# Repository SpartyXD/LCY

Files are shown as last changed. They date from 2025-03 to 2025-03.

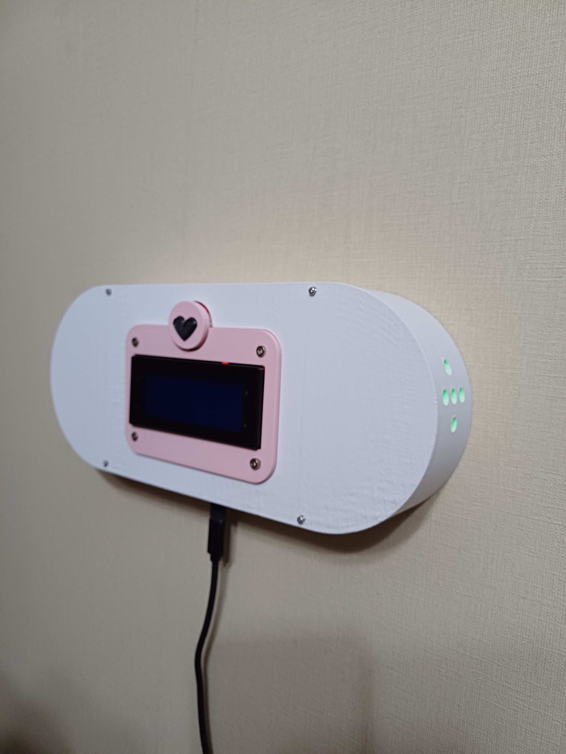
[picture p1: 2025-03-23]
Images/Foto bonita.jpg

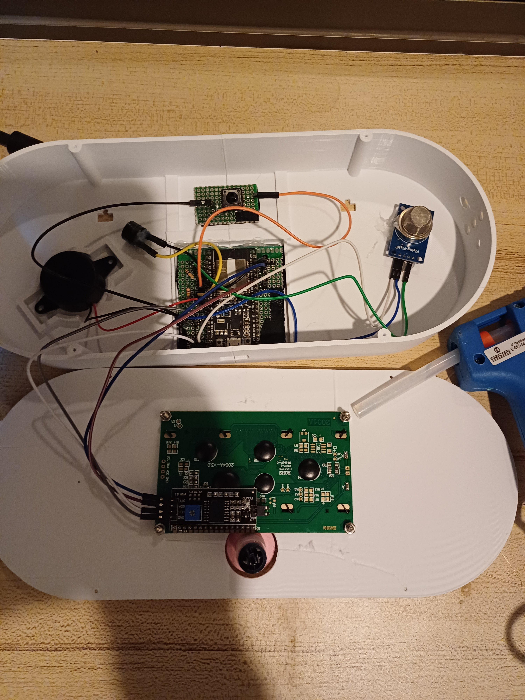
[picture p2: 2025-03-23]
Images/Circuito interno.jpg

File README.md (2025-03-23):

# LCY
Robot que le hice a mi abuelita para que pueda recibir mensajes / estar atenta al gas de la cocina :p 

Puede ser impreso con la combinacion de colores que quieras!

## Proceso de desarrollo
El robot tuvo cambios drasticos en el diseño principalmente porque no calcule bien el espacio de mi impresora 3D, asi que el chasis viene dividido en 2 partes (left - right)

La idea es imprimir una de cada pieza y el circuito hacerlo en una perfboard siguiendo las conexiones que estan en el mockup (pines a eleccion libre)

Implementacion completa

Ensamble

Render_3D

Primer_mock_up

## Componentes usados
* Sensor MQ-2 de gas
* Buzzer pasivo
* Buzzer activo de 12V
* ESP32 WROOM32 DEVKIT
* Headers / Perfboard / Cables
* Pantalla LCD I2C 20x4
* Switch simple (boton)

## Implementacion
El codigo viene listo a modo de proyecto en PlatformIO, solo se debe crear un nuevo proyecto y copiar la carpeta **/src** junto al archivo **platform.ini**.
Para poder usar la funcionalidad de mensajes, se debe crear un bot el telegram usando BOTFather y reemplazando la id en el archivo **chatbot.h** eso, junto a colocar la clave de tu internet en el archivo **main.cpp**

## Modos

### Idle
Pantalla apagada actualizando mediciones de gas y chequeando mensajes entrantes

### Sensor de gas
Al apretar el boton en modo idle se cambia a este modo: muestra la medicion actual del sensor de gas

### Mensajes
Se activa cuando se recibe un mensaje en el bot de telegram, se activa el mini buzzer y alerta al usuario que enviaron un mensaje, pulsa el boton para marcarlo como "recibido"

### Fuga de gas
Se activa cuando se detecta un nivel anormal de gas en el ambiente, enciende la alarma principal (muy fuerte) hasta que se aprete el boton indicando que se corto el gas o bien cuando los niveles vuelvan a la normalidad.

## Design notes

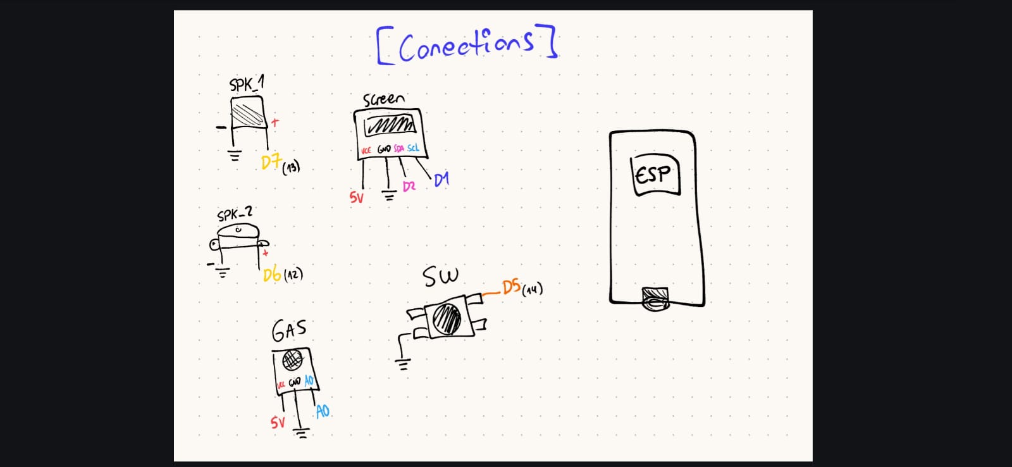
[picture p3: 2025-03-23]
Images/Connections.jpg

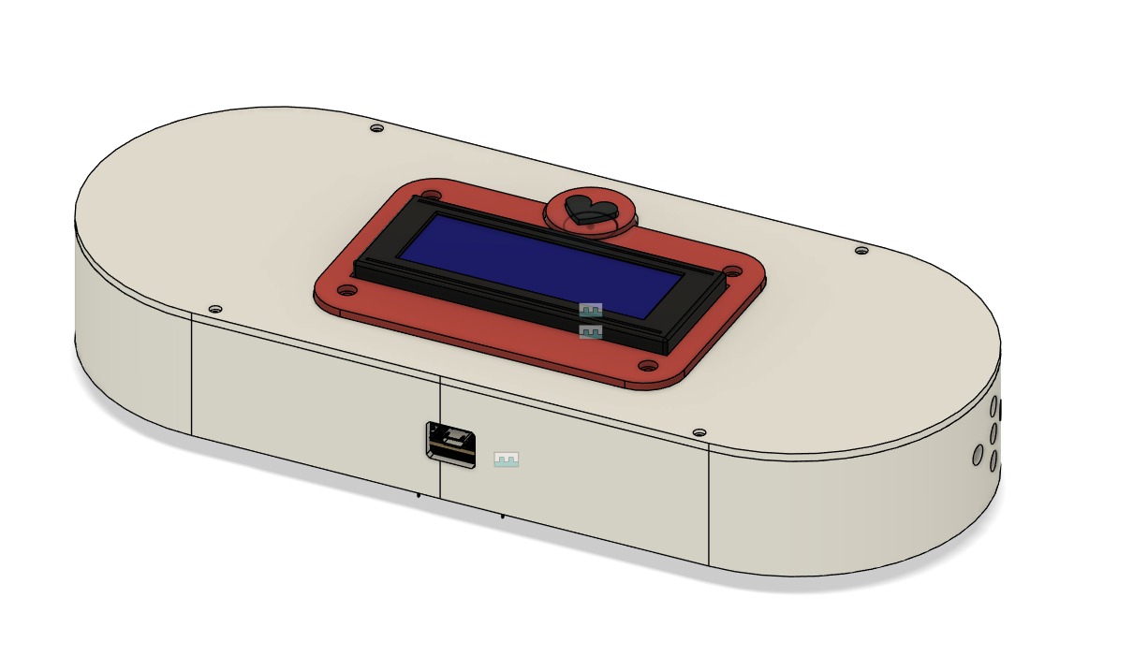
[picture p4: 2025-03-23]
Images/Render_3D.jpg

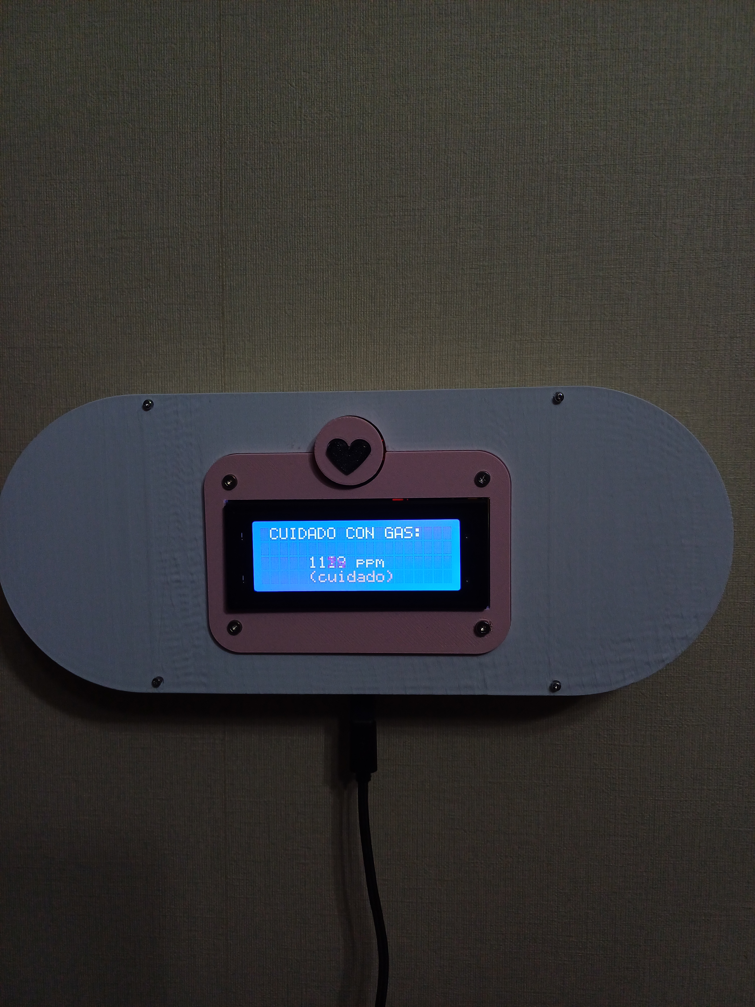
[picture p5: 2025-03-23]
Images/Funcando.jpg

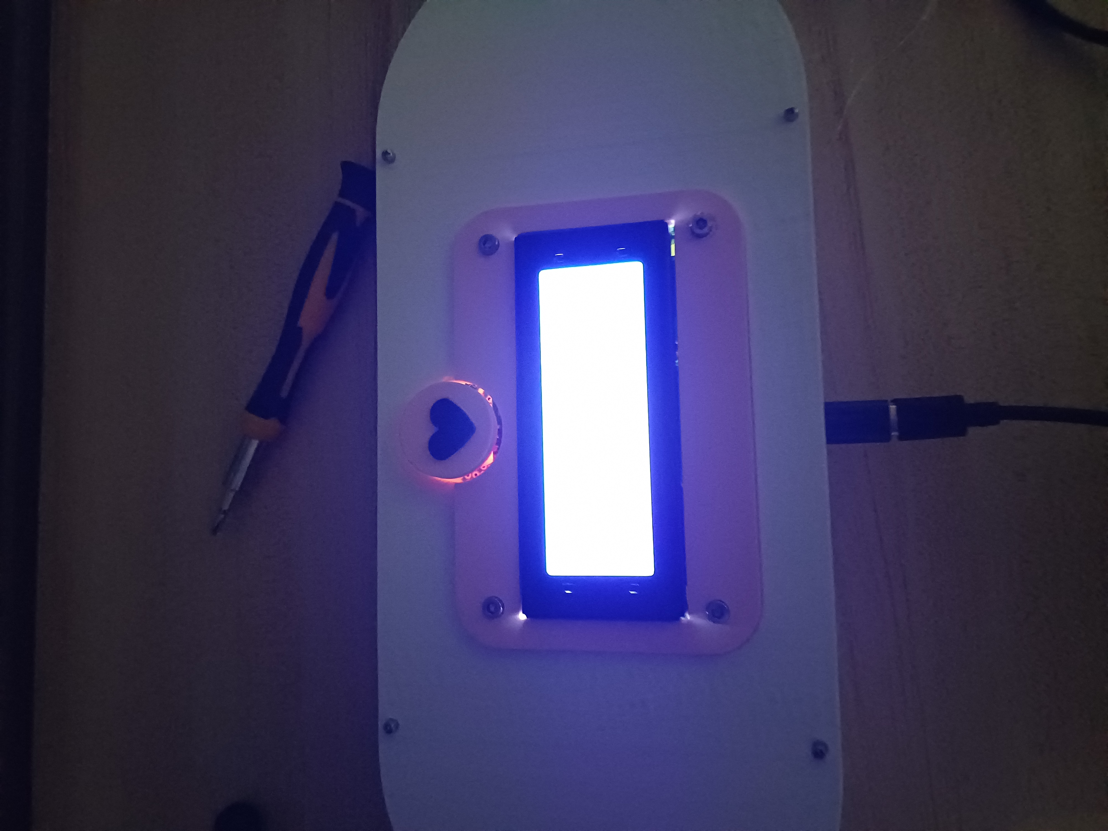
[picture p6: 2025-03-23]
Images/Foto epica.jpg

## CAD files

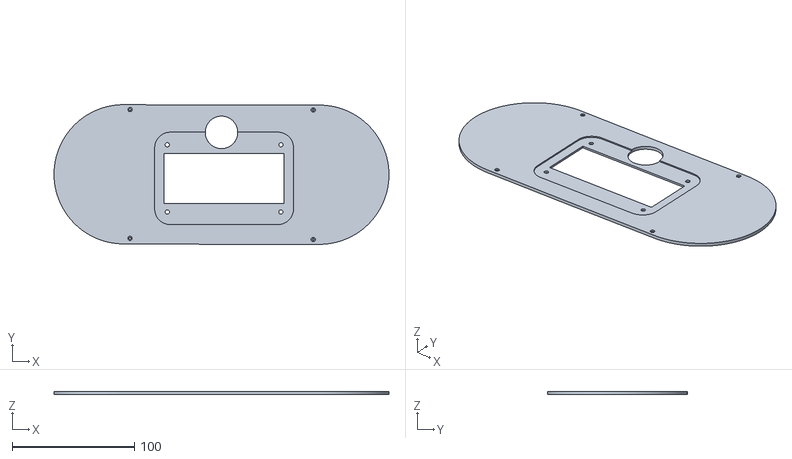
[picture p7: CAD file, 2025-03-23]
3D Files/Top_plate.stl
274.3 x 114.4 x 2.50

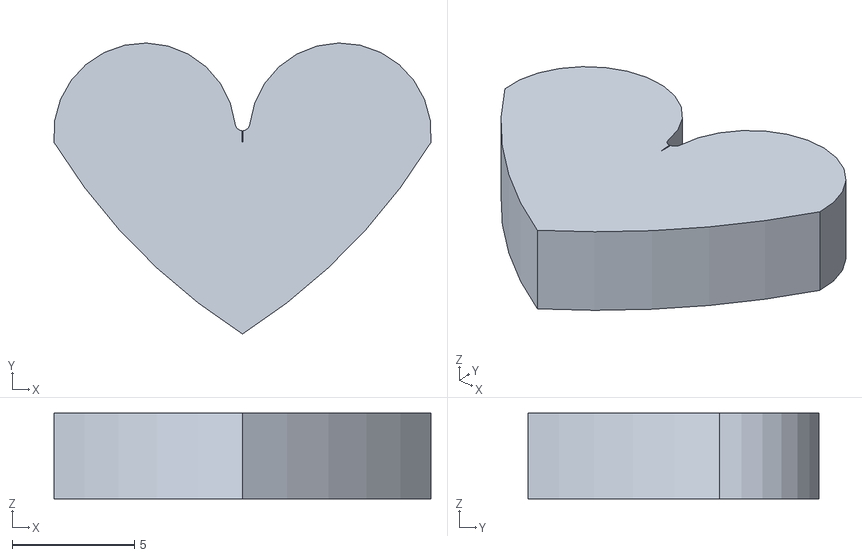
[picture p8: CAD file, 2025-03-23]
3D Files/Keycap_deco.stl
15.4 x 11.9 x 3.50

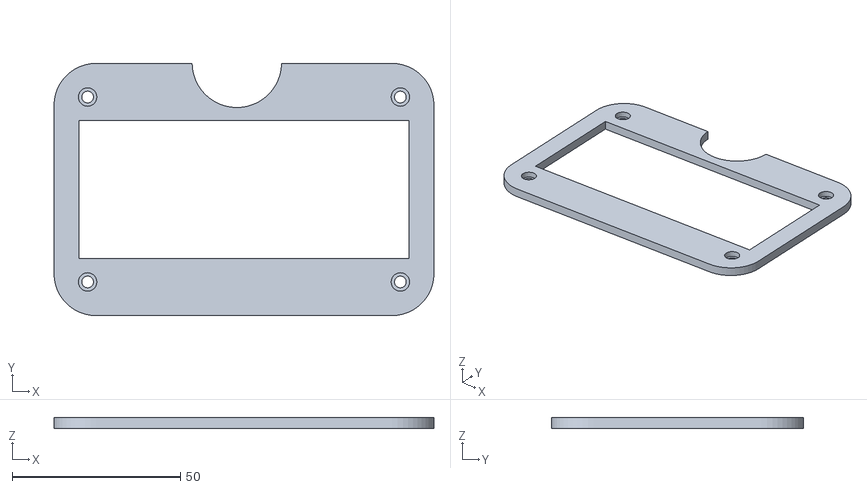
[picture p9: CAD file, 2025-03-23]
3D Files/Screen_deco.stl
113.0 x 75.0 x 3.20

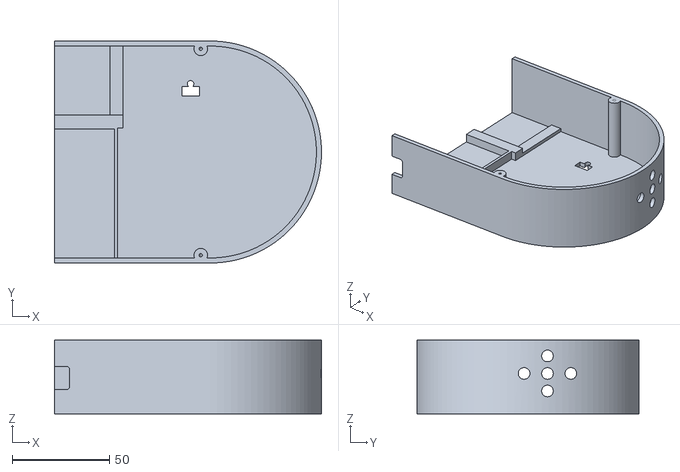
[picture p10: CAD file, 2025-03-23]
3D Files/Right_chasis.stl
137.1 x 114.0 x 38.0

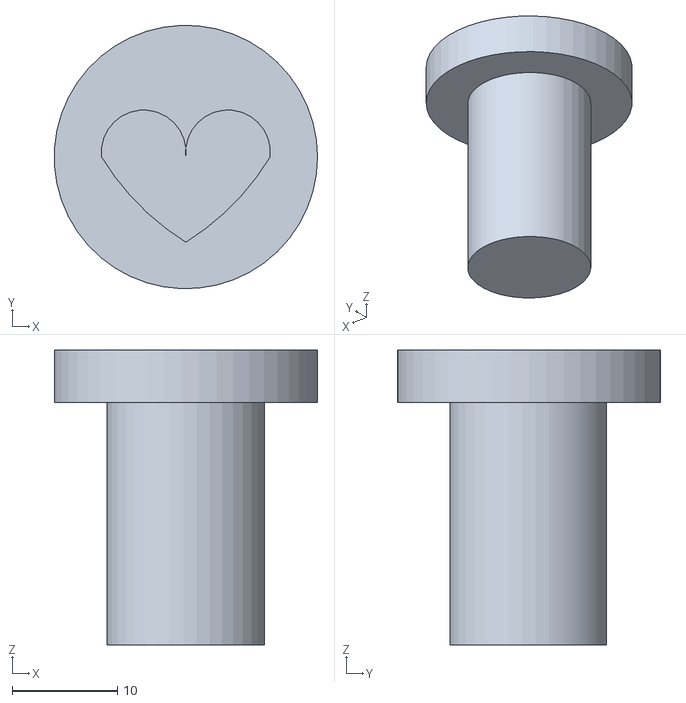
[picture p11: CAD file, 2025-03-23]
3D Files/Keycap.stl
25.0 x 25.0 x 28.0

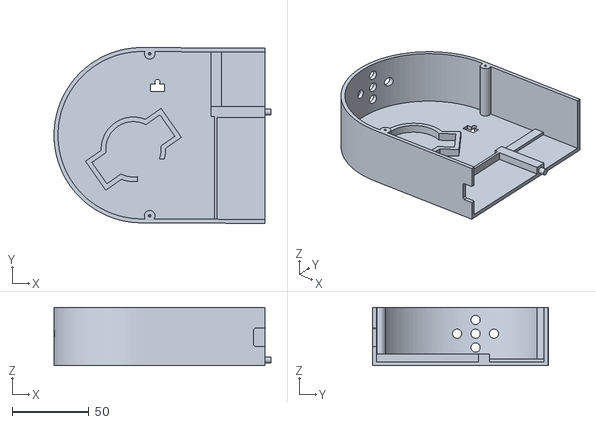
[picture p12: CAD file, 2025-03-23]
3D Files/Left_chasis.stl
141.1 x 114.4 x 38.0

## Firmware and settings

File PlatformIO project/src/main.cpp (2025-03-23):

#include <WiFi.h>
#include <objects.h>
#include <chatbot.h>

//=====================================
//WIFI
#define WIFI_SSID "Your wifi name"
#define WIFI_PASSWORD "Your wifi password"

#define DEBG_MODE false

//===================================
//OBJECTS
LCDScreen screen;
GasSensor sensor;
PassiveBuzzer mini_spk;
ActiveBuzzer alarm_spk;
SwitchButton btn;
ChatBot chatbot;

//===================================
//GLOBALS

// 0-Idle | 1-Message | 2-Gas
int CURRENT_MENU = 0;
String CURRENT_MESSAGE = "";

//===================================

//Functions

void handleMessages(){
    String message = chatbot.receiveMessage();
    chatbot.sendMessage(chatbot.chat_id, "Mensaje recibido 🤖");
    CURRENT_MESSAGE = message;

    //Change menu
    CURRENT_MENU = 1;
}

//===================================

//Menus

struct IdleMode{
    unsigned long idleDelay = 60000; //1 minute
    unsigned long last_change = get_time();
    int CURRENT_FACE = 0;
    bool first_time = true;

    IdleMode(){}

    void run(){
        //Check for button press
        if(btn.isPressed()){
            CURRENT_MENU = 2; //gas
            first_time = true;
            return;
        }


        screen.off_mode();
    }

};


struct MessageMode{
    //Notification
    unsigned long unreadDelay = 60000; //60 seconds
    unsigned long last_notification = get_time();
    unsigned long time_now = get_time();

    MessageMode(){}

    void run(){
        //Check button press
        if(btn.isPressed()){
            CURRENT_MENU = 0;
            mini_spk.successBeep();
            chatbot.sendMessage(chatbot.chat_id, "Mensaje leido 😉");
            last_notification = 0;
            return;
        }

        //Is a command?
        if(CURRENT_MESSAGE[0] == '/'){
            chatbot.sendMessage(chatbot.chat_id, "Comando recibido ✅");
            handleCommand(CURRENT_MESSAGE.substring(1));
            return;
        }

        //Handle notification
        time_now = get_time();
        if(time_now-last_notification > unreadDelay){
            last_notification = time_now;
            mini_spk.alarmBeep();
        }

        screen.printMessage(chatbot.last_message_name, CURRENT_MESSAGE);  
    }


    void handleCommand(String command){
        if(command.substring(0, 8) == "register"){
            chatbot.updateSenderID(command.substring(9), chatbot.chat_id);
            chatbot.sendMessage(chatbot.chat_id, "Usuario registrado: " + command.substring(9));
        }

        CURRENT_MENU = 0;
    }

};


struct GasMode{
    bool snoozed = false;
    bool GAS_LEAK = false;

    unsigned long last_snooze = get_time();
    unsigned long SNOOZE_TIME = 120000; //2 minutes
    unsigned long time_now = get_time();

    int gas_level = 0;
    
    GasMode(){}

    void showGasInfo(String message="Nivel de gas:"){
        //Get info
        gas_level = sensor.get_gas_level();

        //Show
        screen.clear();
        screen.printCenteredTextNumber(message, String(gas_level) + " ppm");
        
        if(sensor.warning())
            screen.printCentered("(cuidado)", 3);

        screen.show();
    }


    void run(){
        //Check if buttonPressed
        if(btn.isPressed()){
            CURRENT_MENU = 0;
            return;
        }

        //Get status
        showGasInfo();
    }


    void alarmMode(){
        //Anti bugs
        if(!snoozed)
            alarm_spk.enable();

        //Check if snoozed
        if(snoozed){
            //Get out of snooze
            time_now = get_time();
            if(time_now-last_snooze > SNOOZE_TIME){
                snoozed = false;
                alarm_spk.enable();
            }

            showGasInfo("CUIDADO CON GAS:");
            return;
        }

        //Alert user
        showGasInfo("CUIDADO CON GAS:");


        //Snooze button
        if(btn.isPressed()){
            snoozed = true;
            alarm_spk.disarm();
            last_snooze = get_time();

            screen.clear();
            screen.printCenteredTextNumber("Silenciado:", String(int(SNOOZE_TIME/60000)) + " minutos");
            screen.show();
            delay(2000);
        }
    }


};

IdleMode idleScreen;
MessageMode messageScreen;
GasMode gasScreen;

//===================================

void setup(){
    if(DEBG_MODE)
        Serial.begin(115200);

    mini_spk.init(SPK_1, 0);
    alarm_spk.init(SPK_2);

    sensor.init(GAS, 950); //Set this number to your calibrated threshold

    screen.init(mini_spk);
    btn.init(SWPIN, mini_spk);

    WiFi.begin(WIFI_SSID, WIFI_PASSWORD);
    chatbot.init();

    screen.loading_screen();
    delay(1000);
}


unsigned long messageCheckDelay = 5000; //5 seconds
unsigned long time_now = get_time();
unsigned long last_check = get_time();

void loop(){
    //Check gas sensor
    if(sensor.dangerous()){
        gasScreen.alarmMode();
        alarm_spk.alarm_mode();
        delay(100);
        return;
    }
    else{
        alarm_spk.disarm();
    }


    //Check for messages
    time_now = get_time();
    if(time_now-last_check > messageCheckDelay){
        last_check = time_now;
        chatbot.update();
    }

    //Handle incoming mesages
    if(chatbot.numNewMessages){
        screen.clear();
        screen.printCentered("Nuevos mensajes...");
        screen.show();

        delay(800);
        handleMessages();
    }
    

    //Corresponding menu
    switch (CURRENT_MENU){
      case 0:
        idleScreen.run();
        break;

      case 1:
        messageScreen.run();
        break;

      case 2:
        gasScreen.run();
        break; 
        
      default:
        break;
    }

    delay(100);
}



//===================================

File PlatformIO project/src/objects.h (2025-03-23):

#ifndef OBJECTS_H
#define OBJECTS_H

#include <parameters.h>
#include <bot_faces.h>

#include <SPI.h>
#include <Wire.h>
#include <LiquidCrystal_I2C.h>

//=================

//SCREEN
#define i2c_Address 0x27 //initialize with the I2C addr 0x3C Typically eBay OLED's
#define SCREEN_WIDTH 20 
#define SCREEN_HEIGHT 4 

// Adafruit_SH1106G display = Adafruit_SH1106G(SCREEN_WIDTH, SCREEN_HEIGHT, &Wire, OLED_RESET);
LiquidCrystal_I2C display(i2c_Address, SCREEN_WIDTH, SCREEN_HEIGHT);

//==========================================================

struct PassiveBuzzer{
    int pin = 0;

    PassiveBuzzer(){}

    void init(int pin, int channel){
        this->pin = pin;
        pinMode(pin, OUTPUT);    
    }

    void beep(unsigned int frec, unsigned int dur){
        tone(pin, frec);
        delay(dur);
        noTone(pin);
    }


    void startupBeep(){
        beep(700, 100);
        beep(900, 100);
    }

    void actionBeep(){
        beep(700, 100);
    }

    void alarmBeep(){
        beep(1000, 200);
        delay(100);
        beep(800, 300);
    }

    void successBeep(){
        beep(700, 100);
        delay(50);
        beep(1000, 100);
        delay(50);
        beep(1300, 100);
    }

    void gamblingBeep(){
        beep(700, 100);
        delay(50);
        beep(1000, 100);
        delay(200);
    }

    void sadBeep(){
        beep(1300, 100); 
        delay(50);
        beep(1000, 100); 
        delay(50);  
        beep(700, 100);
        delay(50);
        beep(500, 200);
    }

    void celebrationBeep(){
        beep(1000, 200);
        delay(300);
        beep(800, 300);
        delay(300);
        beep(600, 300);    
    }

    void angryBeep(){
        beep(600, 100);
        delay(50);
        beep(800, 100);
        delay(200);  
    }

};


struct ActiveBuzzer{
    int pin = 0;
    bool active = false;
    bool enabled = true;

    unsigned long ALARM_DELAY = 2000;
    unsigned long time_now=0;
    unsigned long last_alarm=0;

    void _update(){
        if(!enabled){
            digitalWrite(pin, LOW);
            return;
        }

        if(active)
            digitalWrite(pin, HIGH);
        else
            digitalWrite(pin, LOW);
    }

    ActiveBuzzer(){}

    void init(int pin, unsigned long alarm_delay=1000){
        this->pin = pin;
        ALARM_DELAY = alarm_delay;
        pinMode(pin, OUTPUT);
        digitalWrite(pin, LOW);
    }

    void beep(unsigned int dur){
        digitalWrite(pin, HIGH);
        delay(dur);
        digitalWrite(pin, LOW);
    }

    void alarm_mode(){
        time_now = get_time();

        if(time_now-last_alarm <= ALARM_DELAY)
            return;
        
        last_alarm = time_now;
        active = !active;
        _update();
    }

    void enable(){
        enabled = true;
        _update();
    }

    void disarm(){
        enabled = false;
        _update();
    }

};


struct SwitchButton{
    int swpin, swState;
    PassiveBuzzer* spk;

    //Debounce
    unsigned long debounce = 50;
    unsigned long last_check = 0;
    unsigned long time_now = 0;
    bool last_state = HIGH;

    SwitchButton(){}


    void init(int sw, PassiveBuzzer &spk){
        swpin = sw;
        this->spk = &spk;

        pinMode(sw, INPUT_PULLUP);
        last_state = digitalRead(sw);
        last_check = millis();
    }

    //Is switch pressed?
    bool isPressed(){
        time_now = get_time();

        if(time_now-last_check <= debounce)
            return false;

        last_check = time_now;
        swState = digitalRead(swpin);

        if(swState == LOW && last_state == HIGH){
            spk->actionBeep();
            last_state = swState;
            return true;
        }

        last_state = swState;
        return false;
    }
};


struct LCDScreen{
    int centerX = 0;
    int centerY = 0;

    int cursorX = 0;
    int cursorY = 0;
    PassiveBuzzer* spk;

    LCDScreen(){}

    void init(PassiveBuzzer &spk){
        centerX = (SCREEN_WIDTH / 2) - 1;
        centerY = (SCREEN_HEIGHT / 2) - 1;
        this->spk = &spk;

        display.init();  
        display.clear();     
        display.backlight();
        display.display();
        delay(2000);
    }


    void off_mode(){
        display.noBacklight();
        display.clear();
        display.display();
    }

    void show(){
        display.backlight();
        display.display();
    }


    void clear(){
        display.clear();
    }


    void moveCursor(int x, int y){
        cursorX = x;
        cursorY = y;
        display.setCursor(x, y);
    }

    void header(String title){
        printCentered(title, 0);
    }

    void loading_screen(){
        for(int i=0; i<=100; i+=20){
            clear();
            printCenteredTextNumber("Cargando...", String(i) + "%");
            show();

            delay(800);
        }

        clear();
        printCentered("L.C.Y");
        show();
        spk->startupBeep();
    }


    void print(String message){
        if(cursorX + message.length() >= SCREEN_WIDTH)
            cursorY++;
        cursorX += message.length();
        display.print(message);
        moveCursor(cursorX, cursorY);
    }

    
    void printCentered(String message, int row=1){
        //Calculate center X
        int center = centerX - (message.length()/2);

        moveCursor(center, row);
        print(message);
    }


    void printCenteredTextNumber(String text, String number){
        clear();
        header(text);
        printCentered(number, 2);
        moveCursor(0, 3);
    }


    void printMessage(String from, String message){
        clear();
        header(from + ":");
        moveCursor(0, 2);
        print(message);
        show();
    }

};


struct GasSensor{
    int pin = 0;
    int THRESHOLD = 1000;
    float MAX_VOLTAGE = 3.3;
    float max_input = 4095;
    int gas_level = 0;
    int last_level = 0;
    unsigned long first_init_time = 0;
    bool warming_up = true;
    #define WARM_UP_TIME 120000


    void _update(){
        gas_level = analogRead(pin);
        gas_level = gas_level*0.8 + last_level*0.2;
        last_level = gas_level;
    }

    GasSensor(){}

    void init(int pin, int threshold=1000, float max_voltage=3.3, float max_input=4095){
        this->pin = pin;
        MAX_VOLTAGE = max_voltage;
        this->max_input = max_input;
        THRESHOLD = threshold;
        first_init_time = get_time();
        pinMode(pin, INPUT);
        _update();
    }

    int get_gas_level(){
        _update();
        return gas_level;
    }

    bool dangerous(){
        _update();

        if(warming_up){
            unsigned long time_now = get_time();
            if(time_now-first_init_time > WARM_UP_TIME)
                warming_up = false;
            return false;
        }

        return gas_level > THRESHOLD;
    }

    bool warning(){
        _update();
        return gas_level > THRESHOLD-100;
    }

};


#endif
